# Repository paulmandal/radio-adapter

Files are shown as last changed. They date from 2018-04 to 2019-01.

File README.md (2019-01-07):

# Radio Adapter Board
Adapter board to connect a Yaesu VX-8DR with a Garmin GPSmap64 and various .mil microphones

V2 PCB
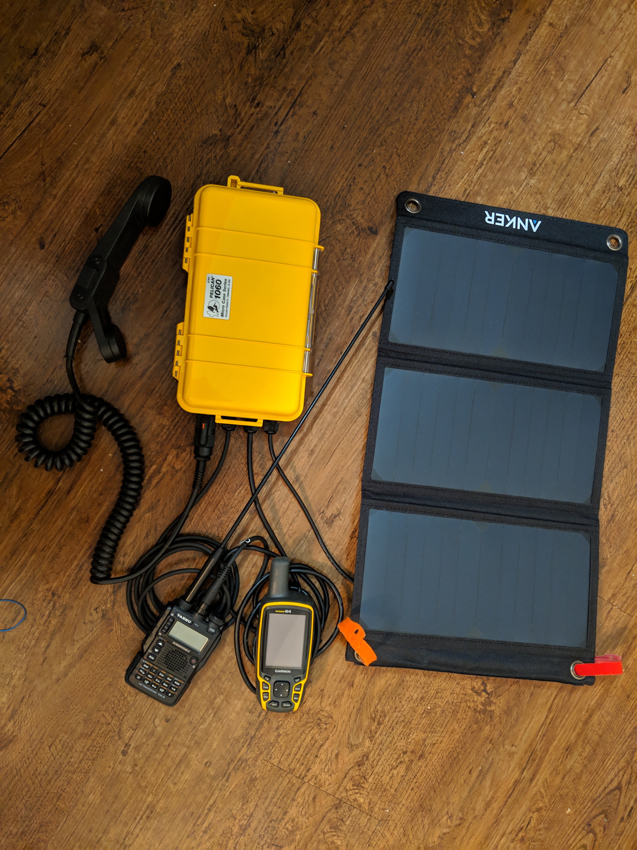
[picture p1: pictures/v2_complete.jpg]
Complete System


# Requirements

- [Arduino](https://www.arduino.cc/en/Main/Software)
- [Eagle](https://www.autodesk.com/products/eagle/free-download)
- You must copy `ucontroller-code/platform.local.txt` to your `$ARDUINO_HOME/hardware/arduino/avr` directory to enable printf formatting of floats

# Table of Contents

| Directory | Contents |
|---|----|
| ucontroller-code | Arduino sketch to translate Garmin GPS NMEA sentences into the fixed-length that the Yaesu VX-8DR expects |
| circuit-board | Eagle circuit diagrams and PCB layouts for the adapter board |
| dev-tools | Various Python scripts that were useful during development |

# Important Note

The ATmega328p chips I got needed to have their fuses set, there is a script `set-fuses.sh` that will do this for you.  You may need to change the programmer from `usbtiny` to whatever you have on hand.

# References

This project borrows heavily from these sources:

[Reverse Engineering the Yaesu VX-8DR GPS Interface](http://lingnik.com/2013/02/09/reverse-engineering-yaesu-vx-8dr-gps-interface.html)

[Dynamic microphone to electret microphone input](http://www.epanorama.net/circuits/dynamic_to_electretinput.html)

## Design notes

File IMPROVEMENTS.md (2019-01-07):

V3:

- SMD audio transformers
- split GND planes to reduce/remove serial data noise from mic/spk
- Add sleep mode to uController code
- maybe -- Move board layout around to allow for shroud around ICSP header
- Add GND/5V pins for quicker debugging and/or more test points

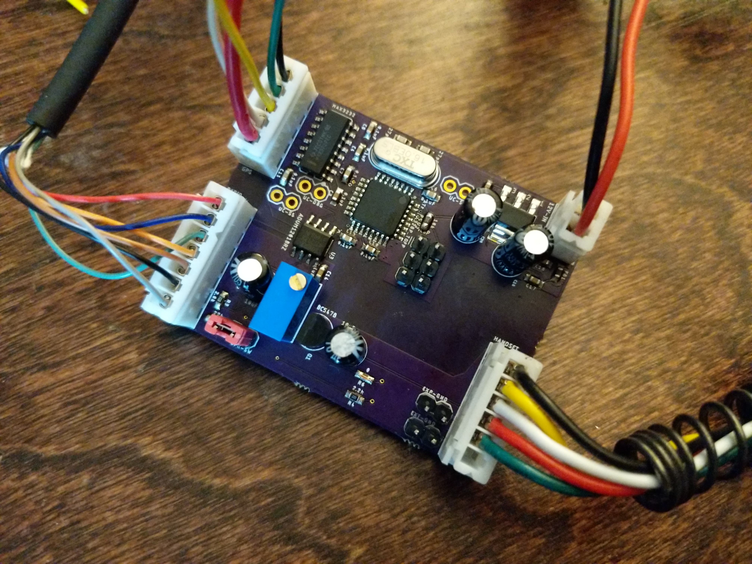
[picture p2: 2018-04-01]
pictures/v1_pcb.jpg

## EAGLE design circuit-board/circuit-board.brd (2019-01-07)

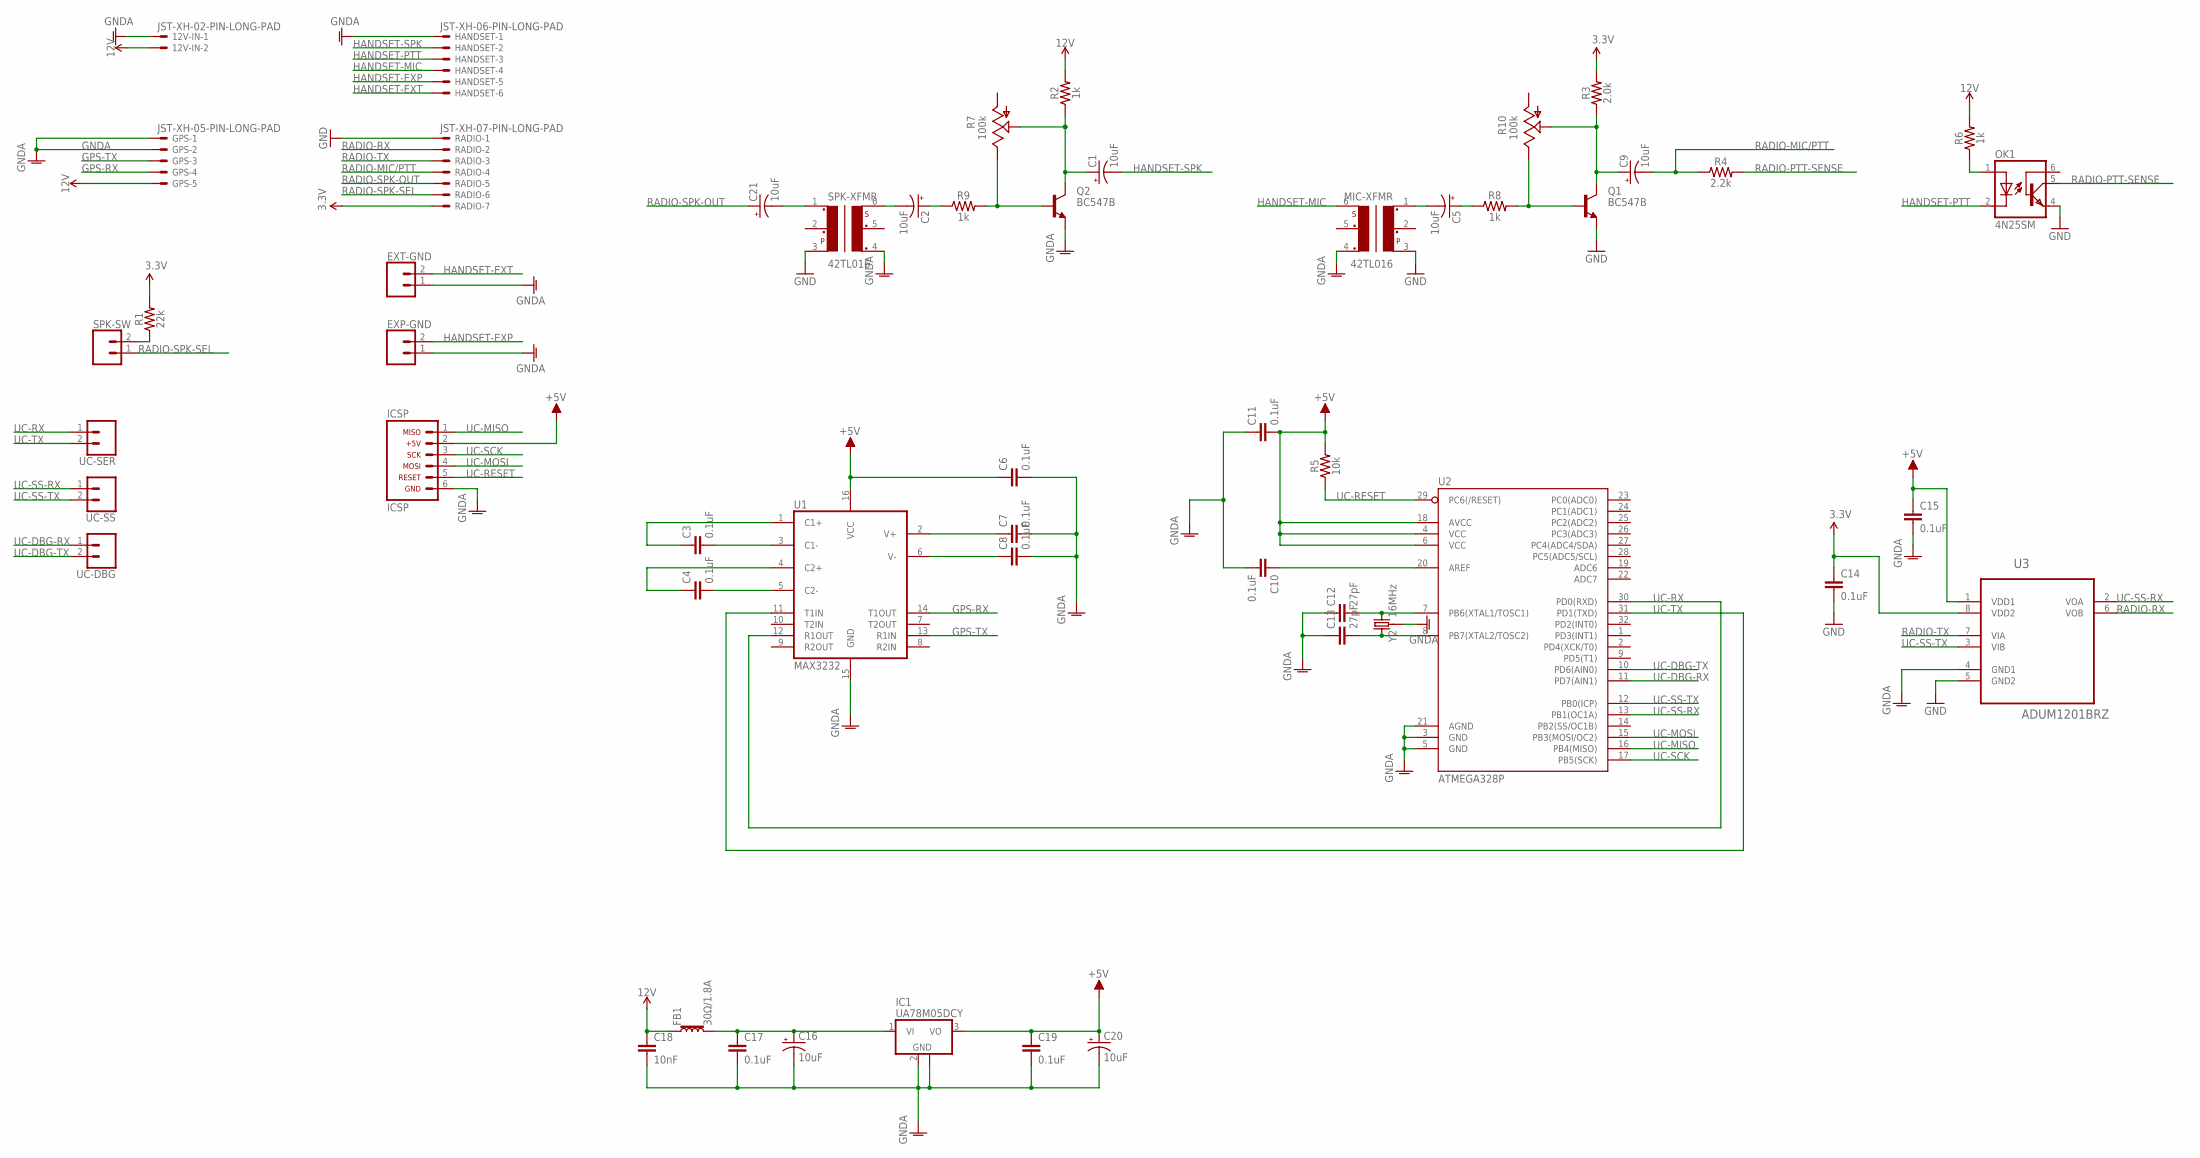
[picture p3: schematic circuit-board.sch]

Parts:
12V-IN: JST-XH-02-PIN-LONG-PAD; JST-XH-02-PACKAGE-LONG-PAD
C1, C2, C5, C9, C16, C20, C21: 10uF; E2,5-5
C3, C4, C6, C7, C8, C10, C11, C14, C15, C17, C19: 0.1uF; 0603
C12, C13: 27pF; 0603
C18: 10nF; 0603
EXP-GND: CONN_02; 1X02
EXT-GND: CONN_02; 1X02
FB1: 30Ω/1.8A; 0603
GPS: JST-XH-05-PIN-LONG-PAD; JST-XH-05-PACKAGE-LONG-PAD
HANDSET: JST-XH-06-PIN-LONG-PAD; JST-XH-06-PACKAGE-LONG-PAD
IC1: UA78M05DCY; SOT223
ICSP: ARDUINO_CONN-ICSP; CONN-2X03
MIC-XFMR: 42TL016; 42TL
OK1: 4N25SM; DIL6-SMD
Q1, Q2: BC547B; TO92
R1: 22k; 0603
R2, R6, R8, R9: 1k; 0603
R3: 2.0k; 0603
R4: 2.2k; 0603
R5: 10k; 0603
R7, R10: 100k; S64W
RADIO: JST-XH-07-PIN-LONG-PAD; JST-XH-07-PACKAGE-LONG-PAD
SPK-SW: CONN_02; 1X02
SPK-XFMR: 42TL016; 42TL
U1: MAX3232; SO16
U2: ATMEGA328P; TQFP32-08
U3: ADUM1201BRZ; SOIC127P600X175-8N
UC-DBG: CONN_02; 1X02
UC-SER: CONN_02; 1X02
UC-SS: CONN_02; 1X02
Y2: 16MHz; CRYSTAL-SMD-3.2X2.5MM

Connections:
3.3V: C14.1, R1.2, R3.2, RADIO.7, U3.8 (VDD2)
12V: 12V-IN.2, C18.1, FB1.1, GPS.5, R2.2, R6.2
+5V: C6.1, C11.2, C15.1, C19.1, C20.+, IC1.3 (VO), ICSP.2, R5.2, U1.16 (VCC), U2.4 (VCC), U2.6 (VCC), U2.18 (AVCC), U3.1 (VDD1)
GND: C14.2, MIC-XFMR.3, OK1.4 (EMI), Q1.1 (E), RADIO.1, SPK-XFMR.3, U3.5 (GND2)
GNDA: 12V-IN.1, C6.2, C7.2, C8.2, C10.2, C11.1, C12.1, C13.1, C15.2, C16.-, C17.2, C18.2, C19.2, C20.-, EXP-GND.1, EXT-GND.1, GPS.1, GPS.2, HANDSET.1, IC1.2 (GND), IC1.4 (GND), ICSP.6, MIC-XFMR.4, Q2.1 (E), SPK-XFMR.4, U1.15 (GND), U2.3 (GND), U2.5 (GND), U2.21 (AGND), U3.4 (GND1), Y2.2 (3), Y2.4 (3)
GPS-RX: GPS.4, U1.14 (T1OUT)
GPS-TX: GPS.3, U1.13 (R1IN)
HANDSET-EXP: EXP-GND.2, HANDSET.5
HANDSET-EXT: EXT-GND.2, HANDSET.6
HANDSET-MIC: HANDSET.4, MIC-XFMR.6
HANDSET-PTT: HANDSET.3, OK1.2 (C)
HANDSET-SPK: C1.-, HANDSET.2
unnamed: C16.+, C17.1, FB1.2, IC1.1 (VI)
unnamed: C2.-, SPK-XFMR.6
unnamed: C9.+, Q1.3 (C), R3.1, R10.S
unnamed: Q1.2 (B), R8.2, R10.E
unnamed: Q2.2 (B), R7.E, R9.2
unnamed: C21.-, SPK-XFMR.1
unnamed: C5.-, MIC-XFMR.1
unnamed: C5.+, R8.1
unnamed: OK1.1 (A), R6.1
unnamed: C2.+, R9.1
unnamed: R1.1, SPK-SW.2
unnamed: C3.2, U1.3 (C1-)
unnamed: C3.1, U1.1 (C1+)
unnamed: C4.2, U1.5 (C2-)
unnamed: C4.1, U1.4 (C2+)
unnamed: C7.1, U1.2 (V+)
unnamed: C8.1, U1.6 (V-)
unnamed: C10.1, U2.20 (AREF)
unnamed: C12.2, U2.7 (PB6(XTAL1/TOSC1)), Y2.3 (2)
unnamed: C13.2, U2.8 (PB7(XTAL2/TOSC2)), Y2.1
RADIO-MIC/PTT: C9.-, R4.1, RADIO.4
RADIO-PTT-SENSE: OK1.5 (COL), R4.2
RADIO-RX: RADIO.2, U3.6 (VOB)
RADIO-SPK-OUT: C21.+, RADIO.5
RADIO-SPK-SEL: RADIO.6, SPK-SW.1
RADIO-TX: RADIO.3, U3.7 (VIA)
SPKAMP: C1.+, Q2.3 (C), R2.1, R7.S
UC-DBG-RX: U2.11 (PD7(AIN1)), UC-DBG.1
UC-DBG-TX: U2.10 (PD6(AIN0)), UC-DBG.2
UC-MISO: ICSP.1, U2.16 (PB4(MISO))
UC-MOSI: ICSP.4, U2.15 (PB3(MOSI/OC2))
UC-RESET: ICSP.5, R5.1, U2.29 (PC6(/RESET))
UC-RX: U1.12 (R1OUT), U2.30 (PD0(RXD)), UC-SER.1
UC-SCK: ICSP.3, U2.17 (PB5(SCK))
UC-SS-RX: U2.13 (PB1(OC1A)), U3.2 (VOA), UC-SS.1
UC-SS-TX: U2.12 (PB0(ICP)), U3.3 (VIB), UC-SS.2
UC-TX: U1.11 (T1IN), U2.31 (PD1(TXD)), UC-SER.2

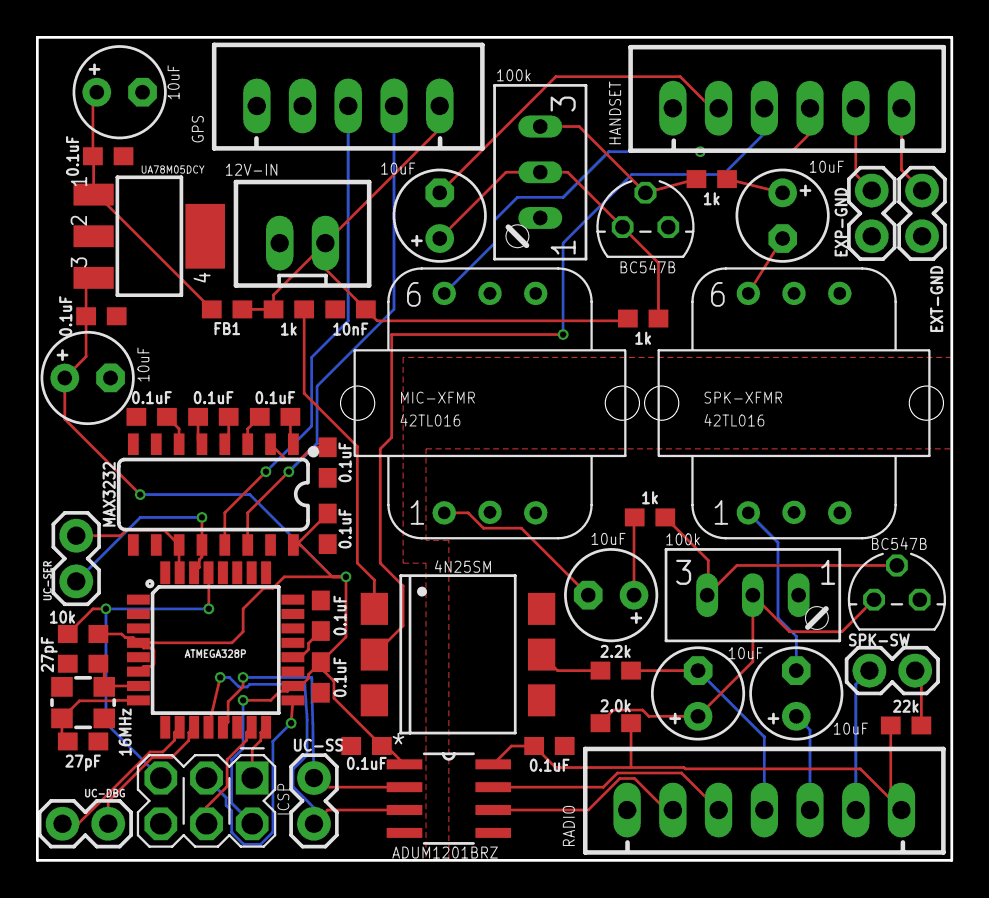
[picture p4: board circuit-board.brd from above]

Board: 2 copper layers, 50.8 x 45.7 mm, 53 parts (0 on the bottom side), 49 nets.

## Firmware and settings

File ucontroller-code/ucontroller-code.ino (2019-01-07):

/**
 * Transforms GPS NMEA messages from the variable-length format used by Garmin (and probably others) into
 * the fixed-lenght format used by the Yaesu VX-8DR
 */
// Uncomment the line below to enable debugging output to the UC-DBG port
//#define DEBUG_PORT_OUTPUT_ENABLED

#include <NeoSWSerial.h>
#include <NeoHWSerial.h>

#include "message_buffer.h"
#include "msg_transform.h"
#include "transform_mapping.h"

#define MSG_BUFFER_SIZE 128

volatile MessageBuffer gpsMessageBuffer(MSG_BUFFER_SIZE);
volatile MessageBuffer debugMessageBuffer(MSG_BUFFER_SIZE);
volatile MessageBuffer queuedMessage(MSG_BUFFER_SIZE);

boolean xferMessages = true;

extern const TransformMapping transformMap[];

NeoSWSerial radioSerial(9, 8);

#ifdef DEBUG_PORT_OUTPUT_ENABLED
NeoSWSerial debugSerial(7, 6);
#endif

void setup() {
  NeoSerial.attachInterrupt(handleGpsInput);
  NeoSerial.begin(4800);
  radioSerial.begin(9600);

#ifdef DEBUG_PORT_OUTPUT_ENABLED
  debugSerial.attachInterrupt(handleDebugInput);
  debugSerial.begin(9600);
  debugSerial.println("Debug serial output - application started.");
#endif
}

/**
 * Main loop -- check for any queued message to be processed
 * TODO: this can be improved by using the microcontroller's sleep functionality and Neo*Serial's interrupt-driven input handling
 */
void loop() {
  if(queuedMessage.length() > 0) {
    handleMessage(queuedMessage.getMessage());
    queuedMessage.clear();
  }
}

/**
 * Handle input interrupt on the GPS port
 */
void handleGpsInput(char c) {
  handleSerialInput(c, gpsMessageBuffer);
}

/**
 * Handle input interrupt on the debug port
 */
void handleDebugInput(char c) {
  handleSerialInput(c, debugMessageBuffer);
}

/**
 * Handle input interrupt -- write the input to a MessageBuffer, check for start/end of message
 * If we hit the end of the message queue the message up for handling
 */
void handleSerialInput(char c, volatile MessageBuffer &messageBuffer) {
    if(c == '$') {
      // New message is beginning
      messageBuffer.clear();
    }
    messageBuffer.write(c);
    if(c == '\n') {
      // Message is finished, queue for processing
      messageBuffer.copyTo(queuedMessage);
      messageBuffer.clear();
    }  
}

/**
 * Handle a completed message -- determine the message type and apply the appropriate transformation
 */
void handleMessage(char *message) {
#ifdef DEBUG_PORT_OUTPUT_ENABLED
  debugSerial.print("GPS->uC:   ");
  debugSerial.print(message);
#endif

  // Check for debugging messages
  if(strncmp(message, "$XFER", 5) == 0) {
    // handle debug message transfer toggle command
    xferMessages = !xferMessages;

#ifdef DEBUG_PORT_OUTPUT_ENABLED
    debugSerial.print("xferMessages: ");
    debugSerial.println(xferMessages);
#endif
  }

  if(!xferMessages) {
    // No need to process messages if we're not sending them to the radio
    return;
  }

  // Determine the message type and apply the appropriate transform
  char *outputMessage = NULL;
  for(int i = 0 ; i < (sizeof(transformMap) / sizeof(TransformMapping)) ; i++) {
    if(strncmp(message, transformMap[i].nmeaMessageType, 6) == 0) {
      outputMessage = transformMap[i].transform(message);
      break;
    }
  }

  // Return if no output message was produced by transforms
  if(outputMessage == NULL) {
    return;
  }

  if(strlen(outputMessage) > 0 && xferMessages) {
    sendToRadio(outputMessage);
  }
  free(outputMessage);
}

/**
 * Send a message to the radio and debug serial ports
 */
void sendToRadio(char *message) {
  radioSerial.listen();
  radioSerial.println(message);

#ifdef DEBUG_PORT_OUTPUT_ENABLED
  debugSerial.listen();
  debugSerial.print("uC->radio: ");
  debugSerial.println(message);
#endif
}

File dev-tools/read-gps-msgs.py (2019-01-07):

#!venv/bin/python
"""
Records GPS messages from a Garmin handheld, this is facilitated by a microcontroller configured as a pass-through
 writing messages to a USB serial device
"""
import serial
import signal
import sys

if len(sys.argv) < 2:
    print('Usage {cmd} <serial device>'.format(cmd=sys.argv[0]))
    sys.exit(1)

USB_SERIAL = sys.argv[1]

serial_port = serial.Serial(USB_SERIAL, 9600)

total_msgs = 0


def signal_handler(signal, frame):
    """
    Handle signals from the operating system -- used to close cleanly on Ctrl+C
    """
    print('total msgs: {}'.format(total_msgs))
    serial_port.close()
    sys.exit(0)

signal.signal(signal.SIGINT, signal_handler)

unique_msgs = []

while True:
    line = serial_port.readline()
    line = line.decode('ascii')
    if len(line) > 6:
        msg_type = line[:6]
        if msg_type not in unique_msgs:
            unique_msgs.append(msg_type)
            print('{}    -    {}'.format(msg_type, line[:len(line) - 2]))
    total_msgs += 1

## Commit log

2018-03-18 Almost finished circuit board schematic
    [circuit-board.sch]
2018-03-18 This worked great with my USB soundcard but not at all with the radio, giving up on this approach -- a BC547 does the trick and eliminates a bunch of isolation and some battery usage
    [circuit-board.sch]
2018-03-18 Circuit schematic finalized, laying out PCB now
    [circuit-board.sch]
2018-03-18 Added 0 Ohm resistor to avoid renaming nets, finished initial PCB layout
    [circuit-board.brd, circuit-board.sch]
2018-03-18 Done for tonight, PCB laid out, need to verify ERC/DRC tomorrow
    [circuit-board.brd, circuit-board.sch]
2018-03-18 Moved version message to bottom layer
    [circuit-board.brd]
2018-03-18 Added labels for JST header pins, synced up board+schematic resistor values
    [circuit-board.brd]
2018-03-18 Added voltage regulator, dropped some JSTs, relaid out board, rerouted
    [circuit-board.brd, circuit-board.sch]
2018-03-18 Manually routed some connections
    [circuit-board.brd]
2018-03-18 Manually routed a few more lines
    [circuit-board.brd]
2018-03-18 Board is final, sending to fab shop
    [circuit-board.brd, circuit-board.sch]
2018-03-18 Super-final, extended ground plane near radio JST
    [circuit-board.brd]
2018-03-18 Added some debug output to vx8dr-basic.ino
    [circuit-board.brd]
2018-04-01 Improved README, added picture of finished PCB, reorganized directory structure
    [circuit-board.brd, circuit-board.sch]
2018-12-01 Update scratchpad.txt with V2 feature list Create v2-scratch.sch to prototype V2 board implementation - Add isolation transformers for mic/spk on handset - Add optoisolation for PTT on handset - Add 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
    [v2-scratch.sch]
2018-12-02 Clean up circuit diagrams, prep for prototype
    [v2-scratch.sch]
2018-12-03 Start new circuit board, fix some small circuit design issues
    [circuit-board.brd, circuit-board.sch]
2018-12-06 Lay out circuit board, preliminary
    [circuit-board.brd, circuit-board.sch]
2018-12-07 Minimize V2 board layout
    [circuit-board.brd]
2018-12-07 Add ground planes, routes to V2 board
    [circuit-board.brd, circuit-board.sch]
2018-12-08 Route V2 board manually, fix up silkscreen
    [circuit-board.brd, circuit-board.sch]
2018-12-08 Tweak some resistor values in V2 board based on breadboard testing. Add small input resistors on both amplifying transistors -- this cleans up the mic signal a lot!
    [circuit-board.brd, circuit-board.sch]
2018-12-08 Route new connections for amplifier input resistors
    [circuit-board.brd]
2018-12-08 Tent vias by adjusting viaStopLimit
    [circuit-board.brd]
2018-12-08 Eliminate overlapping parts in V2 board layout
    [circuit-board.brd]
2018-12-16 Fix placement of design/version text on silkscreen -- too bad this already went to the fab :/
    [circuit-board.brd]
2018-12-17 Improve test-ucontroller.py, fix some small bugs, improve output
    [test-ucontroller.py]
2018-12-17 Strip newlines from output in test-ucontroller.py, fix extra newlines in ucontroller-code.ino
    [test-ucontroller.py, ucontroller-code.ino]
2018-12-17 Switch to NeoSWSerial for serial handling, fix an issue where software serial was writing to both ports
    [ucontroller-code.ino]
2018-12-17 Switch to NeoHWSerial for hardware serial input
2018-12-17 Add MessageBuffer class -- this is in preparation to switching to an interrupt-driven model for serial input processing
2018-12-17 Switch to an interrupt-driven model for serial input consumption
2018-12-17 Start switching to a class-based solution for message transformation -- class has various configurable options for padding, prefix/suffix, static fields
2018-12-18 Switch MessageTransform to use pointers to strings instead of String, rename some structs, add skeletons for NMEA message configs, add mapping for NMEA->transform
2018-12-18 Implemented GGA NMEA message transform, added platform.local.txt to enable printf float formatting
2018-12-26 Add shell script to set uController fuses, add note to README.md about it
2018-12-26 Fix an issue where empty messages would be sent to the radio when a mapping to a message transform could not be found
    [ucontroller-code.ino]
2019-01-06 Switched 100/120 ohm resistors in audio amp circuit for 1k resistors -- noise almost eliminated, though serial noise remains.. will need to split up ground planes to clear that up
    [circuit-board.brd, circuit-board.sch]
2019-01-06 Update message transform to not allocate memory for an output message if GPS fix it not found yet, instead we return NULL and check for NULL in the main loop
    [ucontroller-code.ino]

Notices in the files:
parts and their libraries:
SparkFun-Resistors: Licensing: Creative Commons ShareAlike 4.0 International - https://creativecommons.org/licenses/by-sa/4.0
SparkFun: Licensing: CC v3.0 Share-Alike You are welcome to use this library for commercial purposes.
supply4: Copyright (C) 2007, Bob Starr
